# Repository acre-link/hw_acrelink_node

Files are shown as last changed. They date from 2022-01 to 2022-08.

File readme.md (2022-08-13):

# AcreLink Node
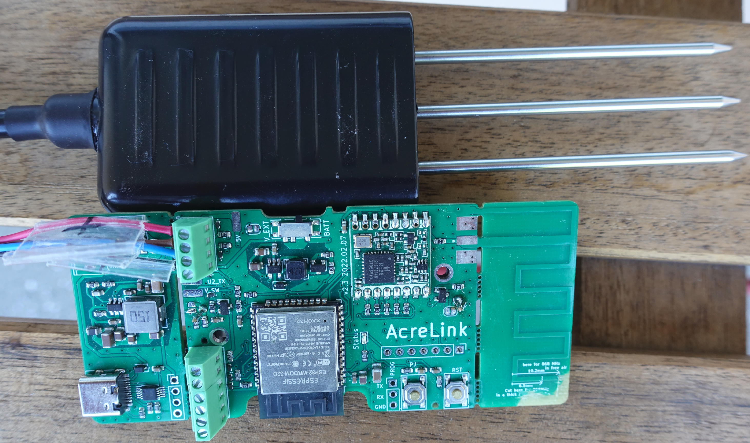
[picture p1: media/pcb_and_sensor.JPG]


- Designed for a sleep current around 6 to 7 uA. 
- ESP32
- RFM95 Lora Module
- 868MHz PCB antenna, can be cut off and replaced by an SMA connector
- AA size lithium battery driven: (LS14500 Lithium-Thionyl-Chlorid or LifePo4 possible)
- Boost converter to supply sensors with stable 5V. Can be switched off for low current sleep mode
- External connector for Onewire, analog inputs and I2C including ESD protection with very low current TVS diodes
- Sensing battery voltage. Can be disabled for low sleep current
- Red led for signaling activity
- SPI header for external connection. 
- Mechanical switch to select battery of external power supply 
- Separate removable pcb section with wide range power supply 5 - 25V,  USB-C connector and USB-UART adapter for programming
- Enableable current measurement at GND level with 1 Ohm Resistor and low pass filtering. 
- Switchable Onewire power, data and datapullup, I2C power and pull ups. 

## 3D Preview 
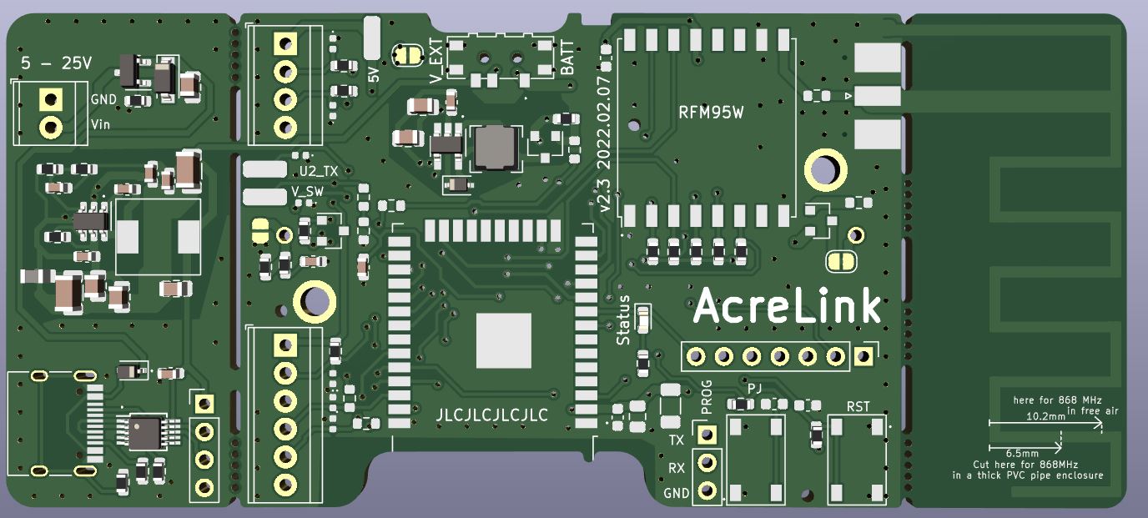
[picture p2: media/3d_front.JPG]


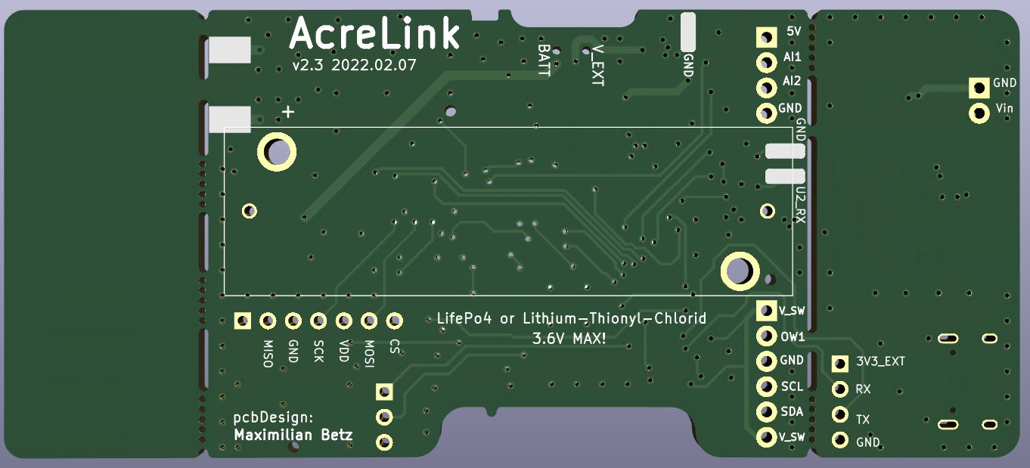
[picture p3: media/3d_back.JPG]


## Pin Mapping ESP32
- AnalogInput1 : PIN13  GPIO14  ADC2_CH6
- Analog Bat   : PIN16  GPIO13  ADC2_CH4 
- AnalogInput2 : PIN11 GPIO26   ADC2_CH9
- I2C SDA	   : PIN33 GPIO21 		
- I2C SCL 	   : PIN36  GPIO22     
- UART2_RX     : PIN27 GPIO16        
- UART2_TX     : PIN28 GPIO17 		 
- 5V Buck EN   : PIN12 GPIO27 		
- LED_Signal   : PIN9 GPIO33
- RFM_MISO     : PIN31  GPIO19 
- RFM_MOSI     : PIN37  GPIO23 
- RFM_SCK      : PIN30  GPIO18
- RFM_CS       : PIN29  GPIO5
- RFM_RST      : PIN23  GPIO15 
- RFM_IRQ/DIO0 : PIN26  GPIO4 
- RFM_DIO1     : PIN8   GPIO32 	

## Links
- Antenna Design: https://github.com/cernohorsky/LoRa-Node  
- Selected soil sensor: https://de.aliexpress.com/item/1005001411485735.html?gatewayAdapt=glo2deu&spm=a2g0o.9042311.0.0.27424c4dQoBMf8 Supplyvoltage 3.6V - 30V.    Two analog outputs  0 to 2 V  for  soil temperature and soil humidity. ~5mA current consumption at 4V 

### Oher Links for reference
- https://www.metergroup.com/de/environment/produkte/teros-21/

- https://www.metergroup.com/de/environment/produkte/teros-10/

- https://www.metergroup.com/de/environment/

- https://de.aliexpress.com/item/32750933038.html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,searchweb201602_,searchweb201603_

- https://de.aliexpress.com/store/915786

- https://www.ugt-online.de/produkte/bodenkunde/bodenfeuchtetemperaturleitfaehigkeit/sm150t/

- https://www.delta-t.co.uk/product/sm150t/

- https://de.aliexpress.com/item/32793236869.html?spm=a2g0s.8937460.0.0.3a672e0eRfM3vv

- Usefull for pin mapping: https://www.electroniclinic.com/esp32-wroom-32d-pinout-features-and-specifications/ 

- https://github.com/matthijskooijman/arduino-lmic#dio-pins  Lora requires at least DIO0 and DIO1

- https://jackgruber.github.io/2020-04-13-ESP32-DeepSleep-and-LoraWAN-OTAA-join/  Deep sleep lorawan

- SPI SD-Card header  //https://www.sparkfun.com/products/544 

- DC-DC Alternative: TP6841S6

## TODOs (next hw version)
- Cutout around USB-C ?
- Connectionpoint GNG-Current Measurement
- Alternative battery with more capacity: LS14500(2.6Ah), LS17500(3.6Ah) , LS26500(7.7Ah) ?    Solder directly to pcb without holder: LS [14,17,26]500CNA, TADIRAN SL360P  ?
- Change to Keystone 1015. Slightly longer but feel mechanically more robust.

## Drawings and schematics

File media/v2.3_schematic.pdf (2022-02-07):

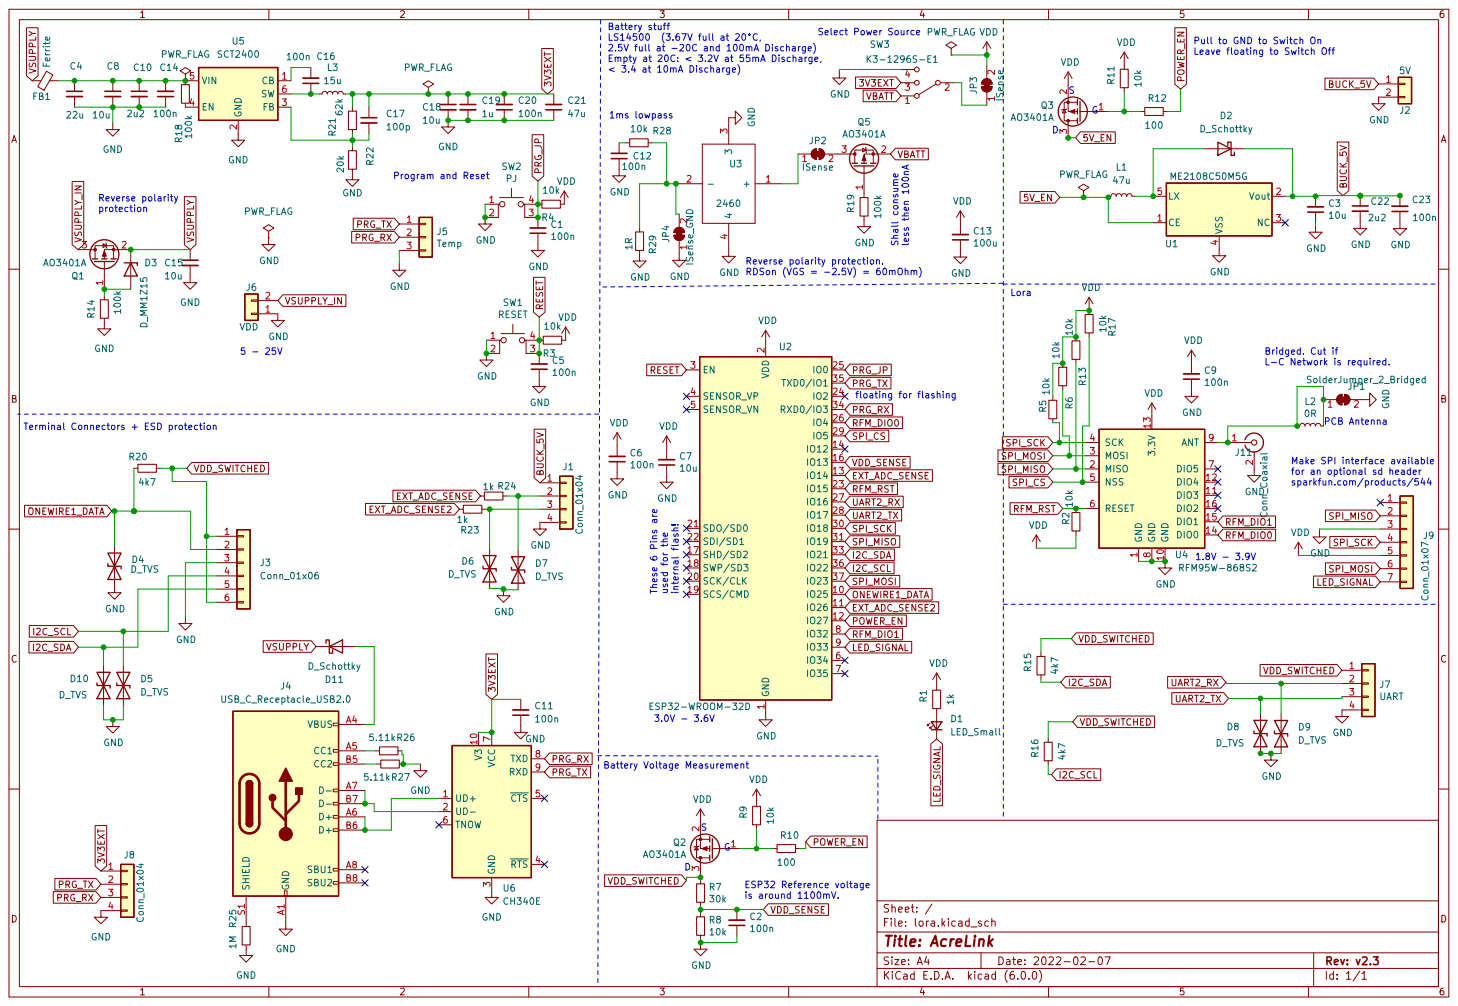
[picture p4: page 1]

Battery stuff
2.5V full at -20C and 100mA Discharge)
Empty at 20C: < 3.2V at 55mA Discharge,
< 3.4 at 10mA Discharge)

2 FB 3 EN 4 VIN 5 SW 6 U5 SCT2400 D8 D_TVS

Pull to GND to Switch On

Leave floating to Switch Off Shall consume less then 100nA

2 SCK/CLK 20 SDO/SD0 21 SDI/SD1 22

1 GND 10 DIO3 11 DIO4 12 3.3V 13 DIO0 14 DIO1 15 DIO2 16 MISO 2 MOSI 3 SCK 4 NSS 5 RESET 6 DIO5 7 GND

Terminal Connectors + ESD protection

for an optional sd header

3 ~{RTS} 4 ~{CTS} 5 TNOW 6 VCC

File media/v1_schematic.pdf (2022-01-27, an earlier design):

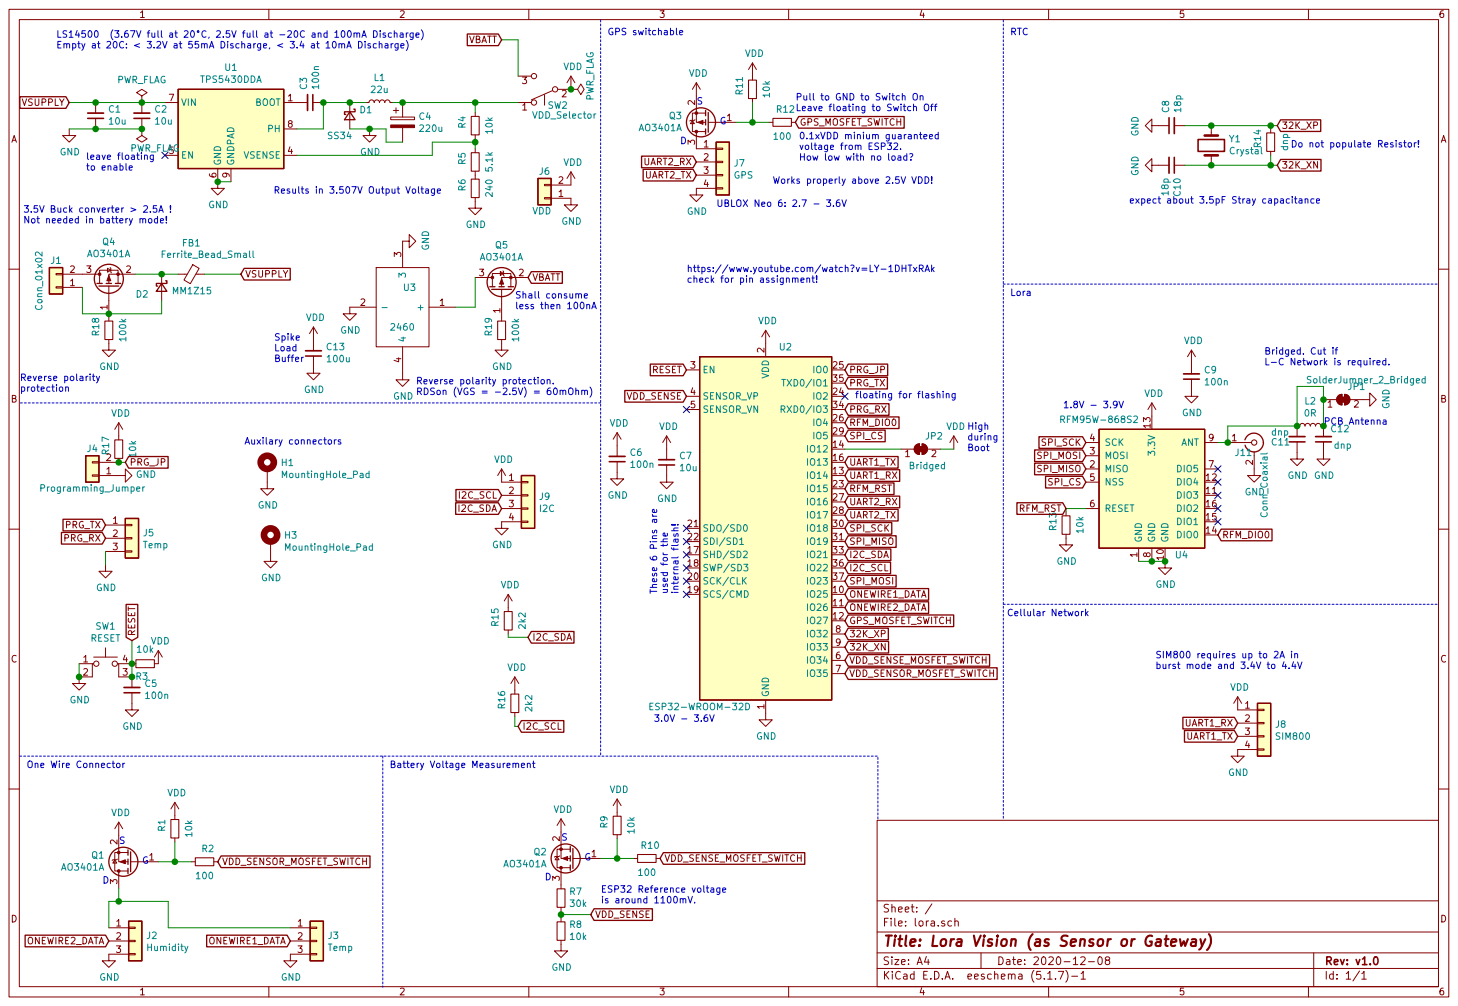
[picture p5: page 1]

LS14500 (3.67V full at 20°C, 2.5V full at -20C and 100mA Discharge)

Leave floating to Switch Off

Do not populate Resistor!

voltage from ESP32. How low with no load? Results in 3.507V Output Voltage

Works properly above 2.5V VDD!

expect about 3.5pF Stray capacitance

during Boot https://www.youtube.com/watch?v=LY-1DHTxRAk
check for pin assignment!

less then 100nA One Wire Connector

L-C Network is required. PCB Antenna D

2 SCK/CLK 20 SDO/SD0 21 SDI/SD1 22

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

SIM800 requires up to 2A in burst mode and 3.4V to 4.4V

Id: 1/1 Title: Lora Vision (as Sensor or Gateway) File: lora.sch Sheet: /

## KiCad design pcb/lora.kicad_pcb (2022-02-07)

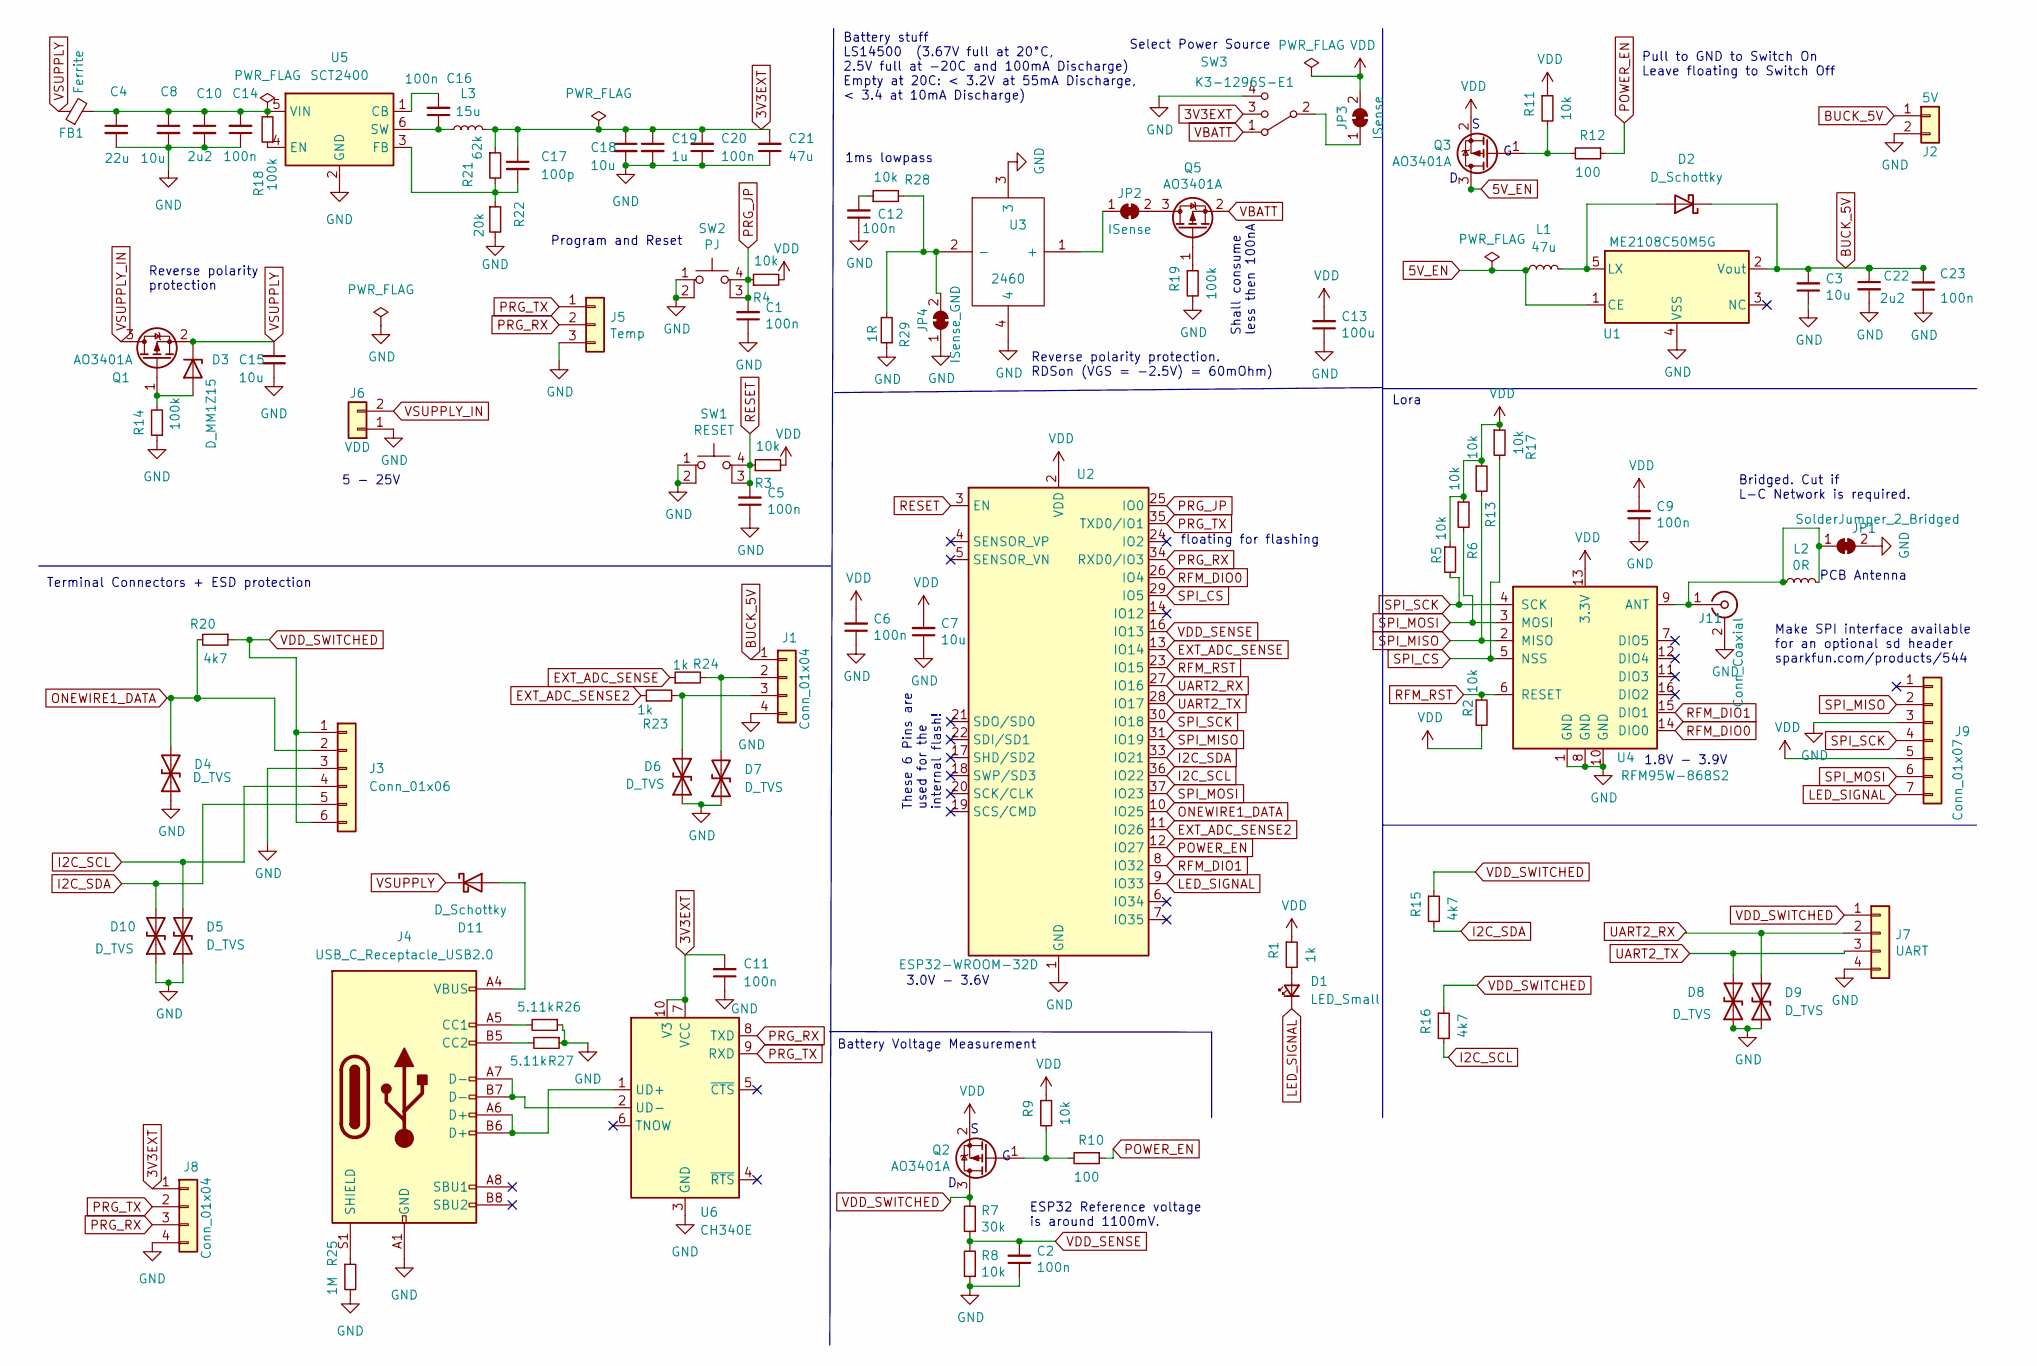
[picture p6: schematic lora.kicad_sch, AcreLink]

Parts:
C1, C2, C5, C6, C9, C11, C12, C14, C16, C20, C23: 100n; C_0603_1608Metric; LCSC C14663
C3, C8, C15, C18: 10u; C_0805_2012Metric; LCSC C440198
C4: 22u; C_1206_3216Metric; LCSC C342620
C7: 10u; C_0805_2012Metric; LCSC C15850
C10, C22: 2u2; C_0805_2012Metric; LCSC C49217
C13: 100u; C_1206_3216Metric; LCSC C15008
C17: 100p; C_0603_1608Metric; LCSC C14858
C19: 1u; C_0603_1608Metric; LCSC C90540
C21: 47u; C_1206_3216Metric; LCSC C96123
D1: LED_Small; LED_0603_1608Metric; LCSC C2286
D2, D11: D_Schottky; D_SOD-323; LCSC C122854
D3: D_MM1Z15; D_SOD-123; LCSC C86235
D4, D5, D6, D7, D8, D9, D10: D_TVS; D_0402_1005Metric; LCSC C2830311
FB1: Ferrite; L_0805_2012Metric; LCSC C1017
J1: Conn_01x04; TerminalBlock_TE_282834-4_1x04_P2.54mm_Horizontal
J2: 5V; pcb_edge_2_1
J3: Conn_01x06; TerminalBlock_TE_282834-6_1x06_P2.54mm_Horizontal
J4: USB_C_Receptacle_USB2.0; USB_C_Receptacle_HRO_TYPE-C-31-M-12; LCSC C167321
J5: Temp; PinHeader_1x03_P2.54mm_Vertical
J6: VDD; TerminalBlock_TE_282834-2_1x02_P2.54mm_Horizontal
J7: UART; pcb_edge_2_2
J8: Conn_01x04; PinHeader_1x04_P2.54mm_Vertical
J9: Conn_01x07; PinHeader_1x07_P2.54mm_Vertical
J11: Conn_Coaxial; SMA_Molex_73251-2120_EdgeMount_Horizontal
JP1: SolderJumper_2_Bridged; jumperhidden
JP2, JP3: ISense; SolderJumper-2_P1.3mm_Bridged_RoundedPad1.0x1.5mm
JP4: ISense_GND; SolderJumper-2_P1.3mm_Bridged_RoundedPad1.0x1.5mm
L1: 47u; L_SWPA4018S; LCSC C83445
L2: 0R; R_0603_1608Metric; LCSC C21189
L3: 15u; SLO0630H; LCSC C182182
Q1, Q2, Q3, Q5: AO3401A; SOT-23; LCSC C15127
R1, R23, R24: 1k; R_0603_1608Metric; LCSC C21190
R2, R3, R4, R5, R6, R8, R9, R11, R13, R17, R28: 10k; R_0603_1608Metric; LCSC C25804
R7: 30k; R_0603_1608Metric; LCSC C22984
R10, R12: 100; R_0603_1608Metric; LCSC C22775
R14, R18, R19: 100k; R_0603_1608Metric; LCSC C25803
R15, R16, R20: 4k7; R_0603_1608Metric; LCSC C23162
R21: 62k; R_0603_1608Metric; LCSC C23221
R22: 20k; R_0603_1608Metric; LCSC C4184
R25: 1M; R_0603_1608Metric; LCSC C22935
R26, R27: 5.11k; R_0603_1608Metric; LCSC C23067
R29: 1R; R_0603_1608Metric; LCSC C22936
SW1: RESET; TS-1187A-C-E-B; LCSC C318889
SW2: PJ; TS-1187A-C-E-B; LCSC C318889
SW3: K3-1296S-E1; LCSC C128955
U1: ME2108C50M5G; SOT-23-5_HandSoldering; LCSC C236790
U2: ESP32-WROOM-32D; ESP32-WROOM-32; LCSC C473012
U3: 2460; Mouser Part Number 534-2460
U4: RFM95W-868S2; HOPERF_RFM9XW_SMD
U5: SCT2400; TSOT-23-6; LCSC C2693819
U6: CH340E; MSOP-10_3x3mm_P0.5mm; LCSC C99652

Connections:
3V3EXT: C11.2, C17.1, C18.1, C19.1, C20.2, C21.2, J8.1, L3.2, R21.1, SW3.3, U6.7 (VCC), U6.10 (V3)
5V_EN: L1.1, Q3.3 (D), U1.1 (CE)
BUCK_5V: C3.2, C22.1, C23.2, D2.1 (K), J1.1, J2.1, U1.2 (Vout)
EXT_ADC_SENSE: R24.1, U2.13 (IO14)
EXT_ADC_SENSE2: R23.1, U2.11 (IO26)
GND: C1.1, C2.1, C3.1, C4.2, C5.1, C6.1, C7.1, C8.2, C9.1, C10.2, C11.1, C12.1, C13.1, C14.1, C15.2, C18.2, C19.2, C20.1, C21.1, C22.2, C23.1, D4.1 (A1), D5.1 (A1), D6.1 (A1), D7.1 (A1), D8.1 (A1), D9.1 (A1), D10.1 (A1), J1.4, J2.2, J3.3, J4.A1 (GND), J4.A12 (GND), J4.B1 (GND), J4.B12 (GND), J5.3, J6.1, J7.4, J8.4, J9.3, J11.2 (Ext), JP1.2 (B), JP4.1 (A), R8.1, R14.1, R19.2, R22.2, R25.2, R26.1, R27.1, R29.1, SW1.1, SW1.2, SW2.1, SW2.2, SW3.4, U1.4 (VSS), U2.1 (GND), U2.15 (GND), U2.38 (GND), U2.39 (GND), U3.3, U3.4, U4.1 (GND), U4.8 (GND), U4.10 (GND), U5.2 (GND), U6.3 (GND)
I2C_SCL: D5.2 (A2), J3.4, R16.2, U2.36 (IO22)
I2C_SDA: D10.2 (A2), J3.5, R15.2, U2.33 (IO21)
LED_SIGNAL: D1.1 (K), J9.7, U2.9 (IO33)
unnamed: C4.1, C8.1, C10.1, C14.2, FB1.2, R18.2, U5.5 (VIN)
unnamed: C12.2, R28.1
unnamed: C16.1, L3.1, U5.6 (SW)
unnamed: C16.2, U5.1 (CB)
unnamed: C17.2, R21.2, R22.1, U5.3 (FB)
unnamed: D1.2 (A), R1.2
unnamed: D2.2 (A), L1.2, U1.5 (LX)
unnamed: D3.2 (A), Q1.1 (G), R14.2
unnamed: D6.2 (A2), J1.3, R23.2
unnamed: D7.2 (A2), J1.2, R24.2
unnamed: D11.2 (A), J4.A4 (VBUS), J4.A9 (VBUS), J4.B4 (VBUS), J4.B9 (VBUS)
unnamed: J4.A5 (CC1), R26.2
unnamed: J4.A6 (D+), J4.B6 (D+), U6.1 (UD+)
unnamed: J4.A7 (D-), J4.B7 (D-), U6.2 (UD-)
unnamed: J4.B5 (CC2), R27.2
unnamed: J4.S1 (SHIELD), R25.1
unnamed: J11.1 (In), JP1.1 (A), L2.1, L2.2, U4.9 (ANT)
unnamed: JP2.1 (A), U3.1 (+)
unnamed: JP2.2 (B), Q5.3 (D)
unnamed: JP3.1 (A), SW3.2
unnamed: Q2.1 (G), R9.2, R10.2
unnamed: Q3.1 (G), R11.2, R12.2
unnamed: Q5.1 (G), R19.1
unnamed: R18.1, U5.4 (EN)
unnamed: JP4.2 (B), R28.2, R29.2, U3.2 (-)
ONEWIRE1_DATA: D4.2 (A2), J3.2, R20.2, U2.10 (IO25)
POWER_EN: R10.1, R12.1, U2.12 (IO27)
PRG_JP: C1.2, R4.1, SW2.3 (K), SW2.4 (A), U2.25 (IO0)
PRG_RX: J5.2, J8.3, U2.34 (RXD0/IO3), U6.8 (TXD)
PRG_TX: J5.1, J8.2, U2.35 (TXD0/IO1), U6.9 (RXD)
RESET: C5.2, R3.1, SW1.3 (K), SW1.4 (A), U2.3 (EN)
RFM_DIO0: U2.26 (IO4), U4.14 (DIO0)
RFM_DIO1: U2.8 (IO32), U4.15 (DIO1)
RFM_RST: R2.1, U2.23 (IO15), U4.6 (RESET)
SPI_CS: R17.2, U2.29 (IO5), U4.5 (NSS)
SPI_MISO: J9.2, R13.2, U2.31 (IO19), U4.2 (MISO)
SPI_MOSI: J9.6, R6.2, U2.37 (IO23), U4.3 (MOSI)
SPI_SCK: J9.4, R5.2, U2.30 (IO18), U4.4 (SCK)
UART2_RX: D9.2 (A2), J7.2, U2.27 (IO16)
UART2_TX: D8.2 (A2), J7.3, U2.28 (IO17)
VBATT: Q5.2 (S), SW3.1
VDD: C6.2, C7.2, C9.2, C13.2, J9.5, JP3.2 (B), Q2.2 (S), Q3.2 (S), R1.1, R2.2, R3.2, R4.2, R5.1, R6.1, R9.1, R11.1, R13.1, R17.1, U2.2 (VDD), U4.13 (3.3V)
VDD_SENSE: C2.2, R7.1, R8.2, U2.16 (IO13)
VDD_SWITCHED: J3.1, J3.6, J7.1, Q2.3 (D), R7.2, R15.1, R16.1, R20.1
VSUPPLY: C15.1, D3.1 (K), D11.1 (K), FB1.1, Q1.2 (S)
VSUPPLY_IN: J6.2, Q1.3 (D)

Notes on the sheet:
3.0V - 3.6V
5 - 25V
floating for flashing
1.8V - 3.9V
Battery stuff LS14500 (3.67V full at 20°C, 2.5V full at -20C and 100mA Discharge) Empty at 20C: < 3.2V at 55mA Discharge, < 3.4 at 10mA Discharge)
Terminal Connectors + ESD protection
These 6 Pins are used for the internal flash!
Program and Reset
PCB Antenna
Bridged. Cut if L-C Network is required.
Select Power Source
1ms lowpass
Battery Voltage Measurement
Pull to GND to Switch On Leave floating to Switch Off
Make SPI interface available for an optional sd header sparkfun.com/products/544
Lora
ESP32 Reference voltage is around 1100mV.
Shall consume less then 100nA
Reverse polarity protection. RDSon (VGS = -2.5V) = 60mOhm)
Reverse polarity protection

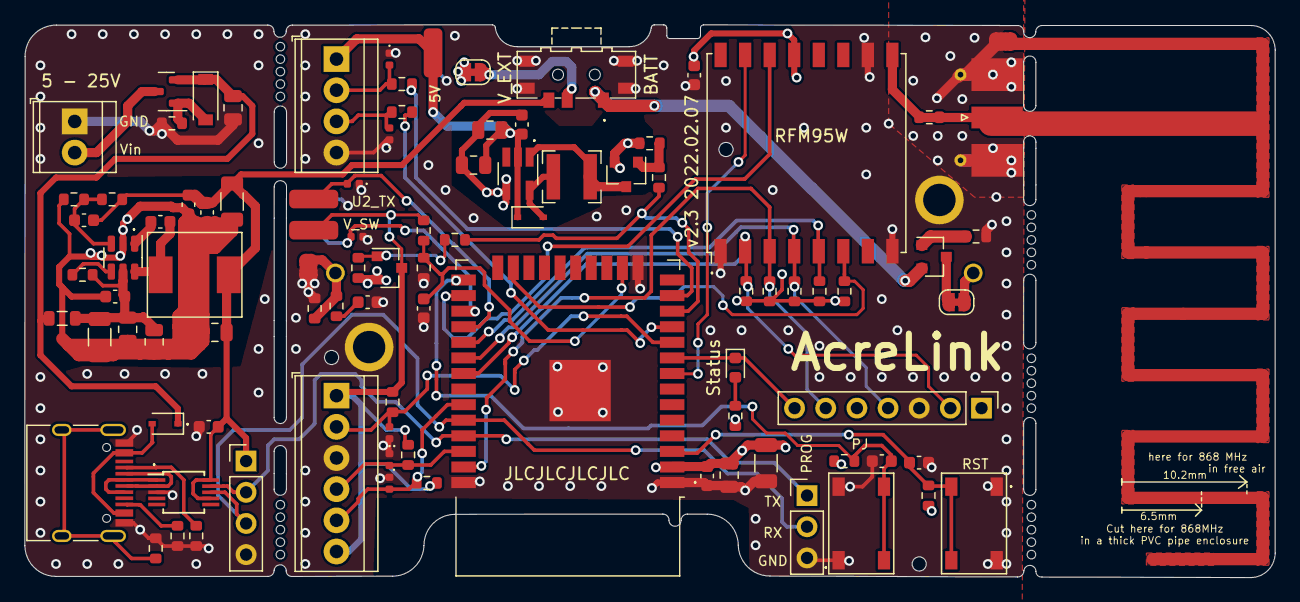
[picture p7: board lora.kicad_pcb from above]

Board: 4 copper layers, 101.9 x 45.1 mm, 94 parts (1 on the bottom side), 55 nets.

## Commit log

2020-11-11 Initial import hw design
    [lora.kicad_pcb, lora.sch]
2020-11-15 minor updates
    [lora.sch]
2020-11-15 finished dc dc power supply.
    [lora.sch]
2020-11-15 nothing major
    [lora.sch]
2020-11-16 removed RTC, added 32KHZ crystal to esp32.
    [lora.sch]
2020-11-16 added reverse polarity protection.
    [lora.sch]
2020-11-19 added reverse polarity protection for battery.
    [lora.sch]
2020-11-19 created first net list. Created initial board and structured the componentes.
2020-11-19 some more structure and 2 additonal layers, first board outlines....
    [lora.kicad_pcb, lora.sch]
2020-11-22 some progress with layout. Added ferrit bead to schematic.
    [lora.kicad_pcb, lora.sch]
2020-11-22 added cutouts for antenna.
    [lora.kicad_pcb, lora.sch]
2020-11-22 added mounting holes for GPS
    [lora.kicad_pcb, lora.sch]
2020-11-22 plotted first gerber files.
    [lora-B_Cu.gbr, lora-B_Mask.gbr, lora-B_Paste.gbr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]
2020-11-22 minor things
    [lora.kicad_pcb, lora.sch]
2020-11-22 schönen Lattenzaun! added Toolingholes, and JLCPCB number location.
    [lora.kicad_pcb]
2020-12-08 - updated pin assignment to recommended pins. - added 100uF capacity to buffer spike loads in battery mode.
    [lora.kicad_pcb, lora.sch]
2020-12-08 updated pcb from schematic.
    [lora.kicad_pcb]
2020-12-08 added page legend.
    [lora.kicad_pcb, lora.sch]
2020-12-09 pads gnd plane connection not solid to improve solderability.
    [lora.kicad_pcb]
2020-12-10 intermediate commit before removing a mounting hole
    [lora.kicad_pcb, lora.sch]
2020-12-10 almost done.. more work than expected to change the connector position and size
    [lora.kicad_pcb, lora.sch]
2020-12-10 finalized design and exchanges 220u capacity with a one in stock.
    [lora.kicad_pcb, lora.sch]
2020-12-10 generated gerber files, BOM, and footprint position files. footprint position file needs manual rotation adjustments.
    [lora-B_Cu.gbr, lora-B_Mask.gbr, lora-B_Paste.gbr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]
2020-12-10 corrected wrong rotation. !!This is the ordered version!!
    [lora-top-pos.csv]
2020-12-11 received the production files from jlcpcb for review.
    [lora-B_Cu.gbr, lora-B_Mask.gbr, lora-B_Paste.gbr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]
2021-01-03 added some more comments for next revision of pcb.
2021-01-10 added some more hints for low sleep current in next revision.
2021-02-01 added cut line for antenna cut in PVC tube enclosure.
    [lora.kicad_pcb]
2021-09-07 corrected GND on input terminal
    [lora.sch]
2021-09-07 remove rfm reset pulldown, add spi pullups, switch for programming added, labels backside added
    [lora.sch]
2021-09-07 add onewire pullup
    [lora.sch]
2021-09-07 remove JP2, add hints for StepUP DCDC
    [lora.kicad_pcb, lora.sch]
2021-09-07 updated part number step up
    [lora.sch]
2021-10-07 added label for antenna length
    [lora.kicad_pcb]
2021-10-20 some steps done towards version 2. Progress recorded in hints.txt
    [lora.sch]
2022-01-27 cleaned up folder structure
    [lora-B_Cu.gbr, lora-B_Mask.gbr, lora-B_Paste.gbr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]
2022-01-27 added v1 schematic to media folder
2022-01-27 figured all GPIOs out
    [lora.kicad_pcb]
2022-01-29 intermediate commit
    [lora.kicad_sch]
2022-01-29 schematic finalized
    [lora.kicad_sch]
2022-01-29 updated layout
    [lora.kicad_pcb, lora.kicad_sch]
2022-01-29 updated some text
    [lora.kicad_pcb]
2022-01-29 added usb - serial and external power supply
    [lora.kicad_pcb, lora.kicad_sch]
2022-01-30 fixed DRC errors
    [lora.kicad_pcb, lora.kicad_sch]
2022-01-30 more silkscreen text
    [lora.kicad_pcb, lora.kicad_sch]
2022-01-30 deleted old kicad v5 files
    [lora.kicad_pcb, lora.sch]
2022-01-30 changed a capacity
    [lora.kicad_pcb, lora.kicad_sch]
2022-01-30 added cutout for cable tie to secure battery
    [lora-B_Cu.gbr, lora-B_Mask.gbr, lora-B_Paste.gbr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]
2022-01-31 added spi header and connected dio1 of rfm95
    [lora-B_Cu.gbl, lora-B_Mask.gbs, lora-B_Paste.gbp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]
2022-01-31 updated readmet
    [lora-B_Cu.gbl, lora-B_Mask.gbs, lora-B_Paste.gbp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]
2022-01-31 added v2.1 pdf schematic
2022-02-06 v2.2 finalized, spi connector added and ground current measurement solder jumper added
    [lora.kicad_pcb, lora.kicad_sch, v2.2_lora.csv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]
2022-02-07 added mouse bites for breakaway tabs
    [lora.kicad_pcb, lora.kicad_sch, v2.3_lora.csv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]
